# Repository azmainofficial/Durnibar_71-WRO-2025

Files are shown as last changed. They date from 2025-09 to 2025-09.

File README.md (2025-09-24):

# WRO-2025 Future Engineers 🛠️ Durnibar_71 🛠️ 

<p align="center">
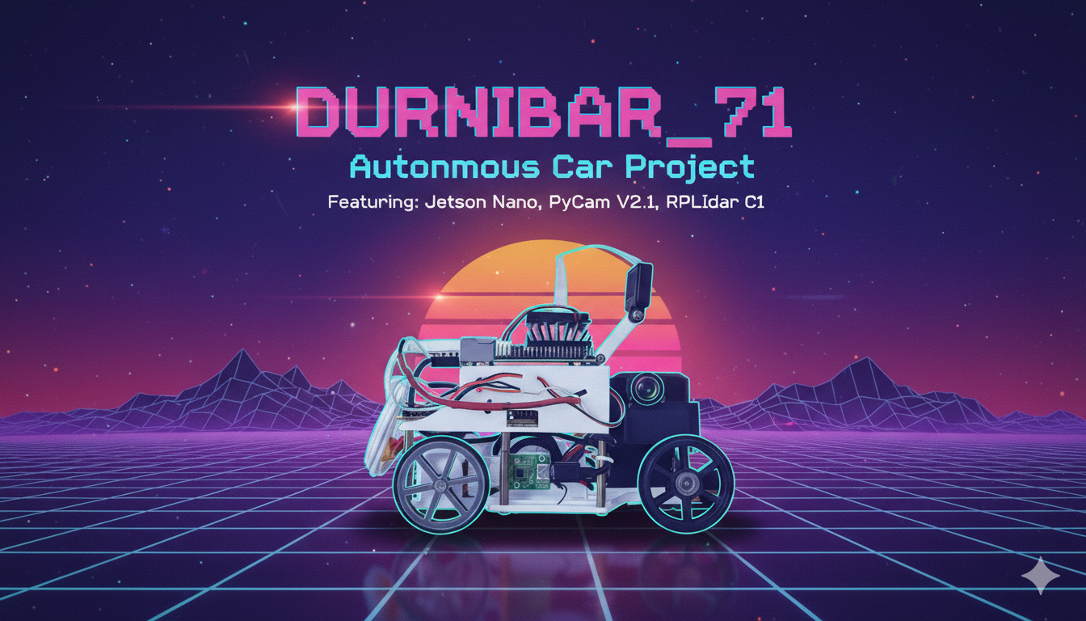
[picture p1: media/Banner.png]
Durnibar_71 Banner
  
</p>

This repository contains our work for the **WRO Future Engineers** category.  
We are building an **Autonomous Car** using **Lidar, Computer Vision, Arduino nano, and Jetson Nano Dev Kit B01**.

---

## 👥 Team - Durnibar_71
- **Azmain Shak Rubayed** – Team Leader, Hardware Developer || [azmiansheikh.nub@gmail.com](mailto:azmiansheikh.nub@gmail.com)
- **Mohit Hasan** - Software Developer || [mohithasan.nub@gmail.com](mailto:azmiansheikh.nub@gmail.com)
---

## 🌟 The Meaning Behind "Durnibar_71"

> *"If the will to win is strong, then any goal can be achieved."*  

This is our **first participation in WRO**, and ever since we began working on this project, we have felt an **indomitable desire** to complete it. That is why we chose the name **"Durnibar"** *(Indomitable / Unstoppable)* — it reflects our relentless effort to give our absolute best, pushing beyond our current limits despite the challenges we faced.  

Every step of this journey has been difficult. We did not have adequate support, so we had to start from scratch and gather every resource on our own. This struggle itself embodies the true spirit of **Durnibar**, a determination to never give up.  

Now, why the **'71**?  
It represents the spirit of the **Bangladesh Liberation War of 1971**. Our independence was achieved not with abundant resources, but with an **unbreakable willpower and focus**. At that time, we were a nation decades behind the rest of the world, yet we shaped our own destiny.  

By carrying the name **Durnibar_71**, we honor that history and commemorate the indomitable willpower of our nation. Just as the people of ’71 stood unstoppable in their pursuit of freedom, we carry the same spirit forward in our journey — in robotics, innovation, and beyond.  

✨ Thank you, everyone, for standing with us in this mission. Together, we move forward with the spirit of **Durnibar_71** — unstoppable, unbreakable, indomitable.  

---

## 📌 Table of Contents
- [🚙 Overview](#-overview)
- [👥 Team Introduction & Information](#-team-introduction--information)
- [📝 Project Description](#-project-description)
- [🔧 Hardware Used](#-hardware-used)
- [💻 Software & Libraries](#-software--libraries)
- [🏆 Competition Challenges](#-competition-challenges)
- [⚠️ Spoilers](#-spoilers)

---
## 🚙 Overview
Our self-driving vehicle prototype, developed for the **WRO Future Engineers 2025** competition, is a fully autonomous robotic system that merges **AI-based decision-making** with precise embedded hardware control.  

The platform is powered by a **Jetson Nano**, serving as the brain for vision and high-level processing, while an **Arduino Nano** handles real-time actuation and sensor management through custom firmware. Sensor data from the **MPU6050 (IMU)** and **QMC5883L (Compass)** is transmitted via serial communication, enabling accurate orientation tracking, drift correction, and smooth navigation.  

The system integrates:  
- **Raspberry Pi Camera v2.1** for image capture and object detection.  
- **MG996R servo motor** and **BTS7960 motor driver** for steering and propulsion control.  
- **1.3" OLED display**, **LED indicators**, **buzzer**, and **3 control buttons** for debugging and feedback.  

Structurally, the vehicle features a **custom PCB** for streamlined connections, alongside a **self-designed chassis**, built for optimal component placement and balance. Power is delivered through a **1000 mAh LiPo battery**, ensuring lightweight mobility and sufficient runtime for competition tasks.  

All functions are distributed between the **Jetson Nano** (core AI/vision algorithms) and the **Arduino Nano** (low-level hardware control), communicating through **PWM, UART, and I²C protocols**. This modular and efficient design ensures the vehicle can **adapt dynamically to track environments**, while maintaining precise actuation and reliable decision-making.  

Altogether, **Durnibar_71** represents an **indomitable and competition-ready platform**, combining embedded intelligence, compact hardware design, and robust autonomy.

## 📂 Repo Structure

- [`media/`](./media) → Images, GIFs, project assets  
- [`models/`](./models) → 3D models, CAD files  
- [`schematic/`](./schematic) → Circuit diagrams, PCB layouts  
- [`software-setup/`](./software-setup) → Installation guides, environment setup  
- [`src/`](./src) → Source code (control, navigation, AI/ML)  
- [`t-photos/`](./t-photos) → Team photos  
- [`v-photos/`](./v-photos) → Vehicle photos  
- [`videos/`](./videos) → Project demo videos  

📜 [`LICENSE`](./LICENSE) → License information  
📖 [`README.md`](./README.md) → Project documentation

## 📸 Visual Views

Here are the reference views of **Durnibar_71**:

| Front View | Back View | Left View |
|---|---|---|
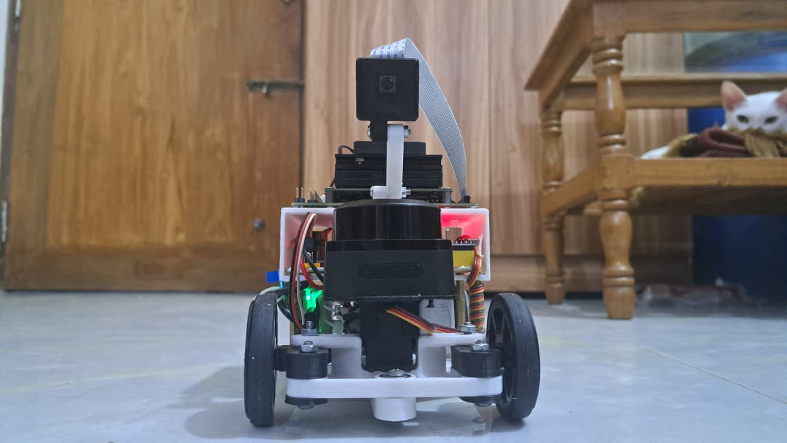
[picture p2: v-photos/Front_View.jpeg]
Front View
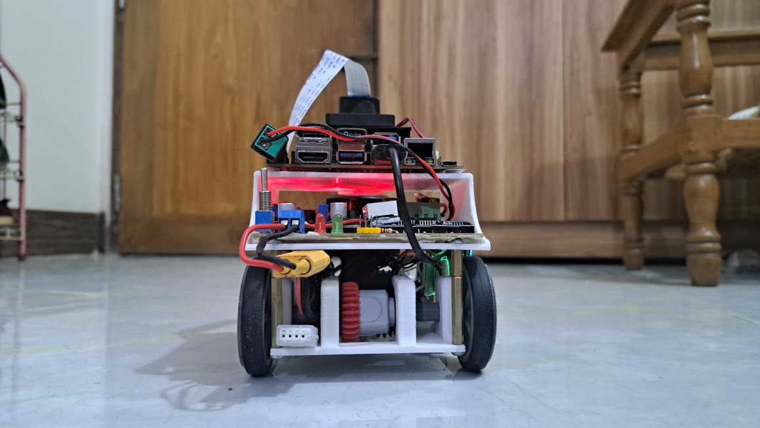
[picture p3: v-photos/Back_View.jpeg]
Back View
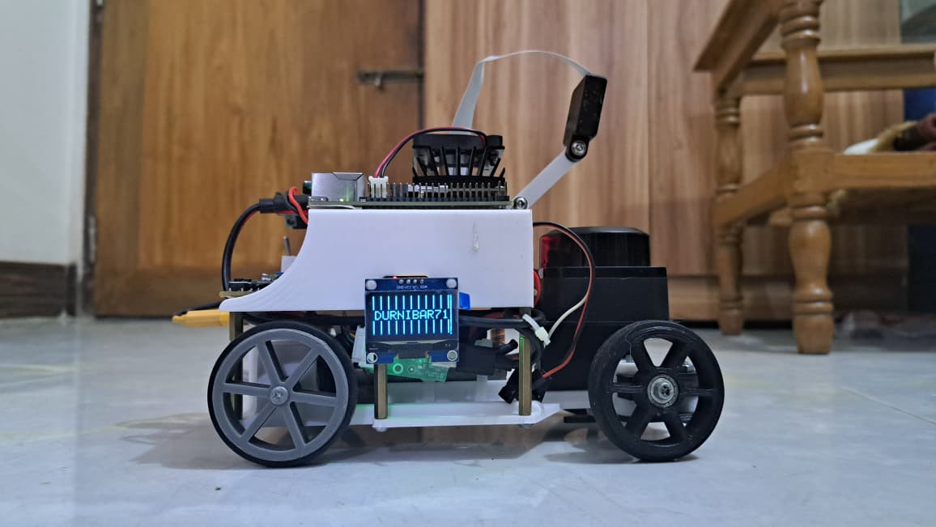
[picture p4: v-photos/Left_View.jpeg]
Left View
|  |  |  |

| Right View | Top View | Bottom View |
|---|---|---|
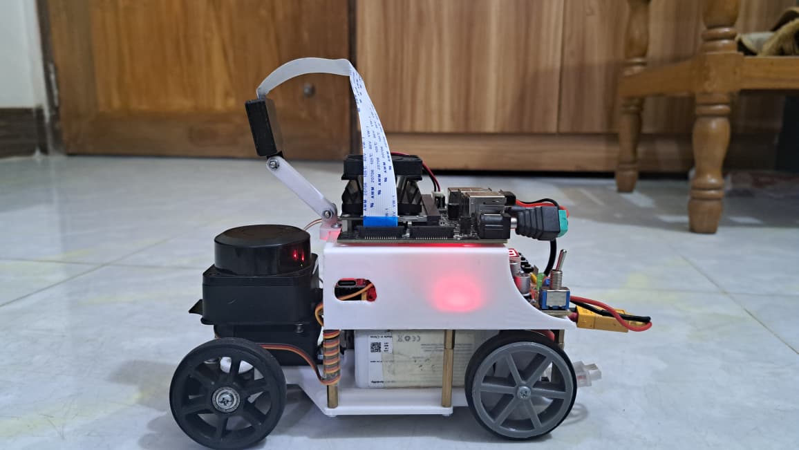
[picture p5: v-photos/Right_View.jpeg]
Right View
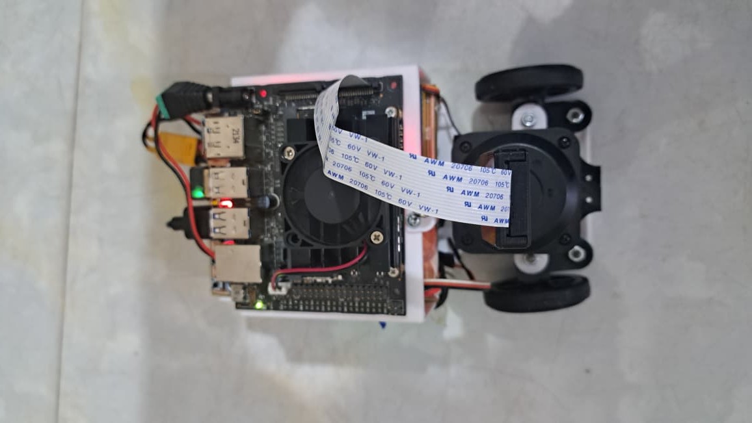
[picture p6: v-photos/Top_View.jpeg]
Top View
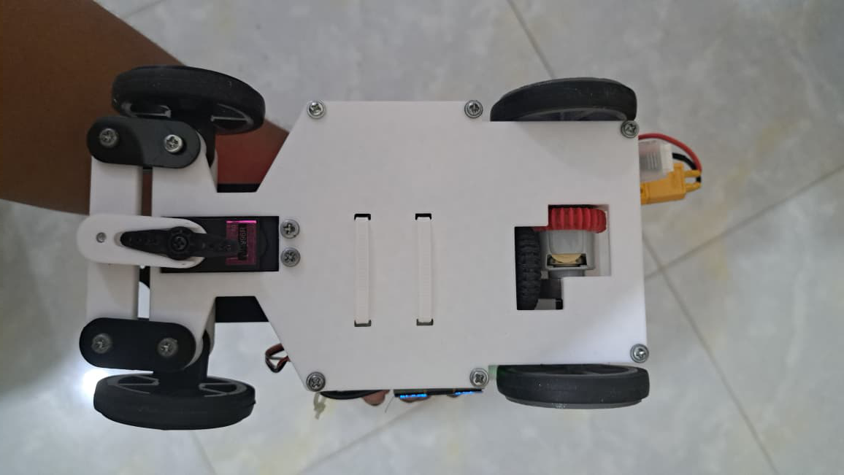
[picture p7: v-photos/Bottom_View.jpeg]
Bottom View
|  |  |  |

---

## 👥 Team Introduction & Information
<table>
  <tr>
    <td align="center" width="300px" style="border: 2px solid #4CAF50; border-radius: 10px; padding: 10px;">
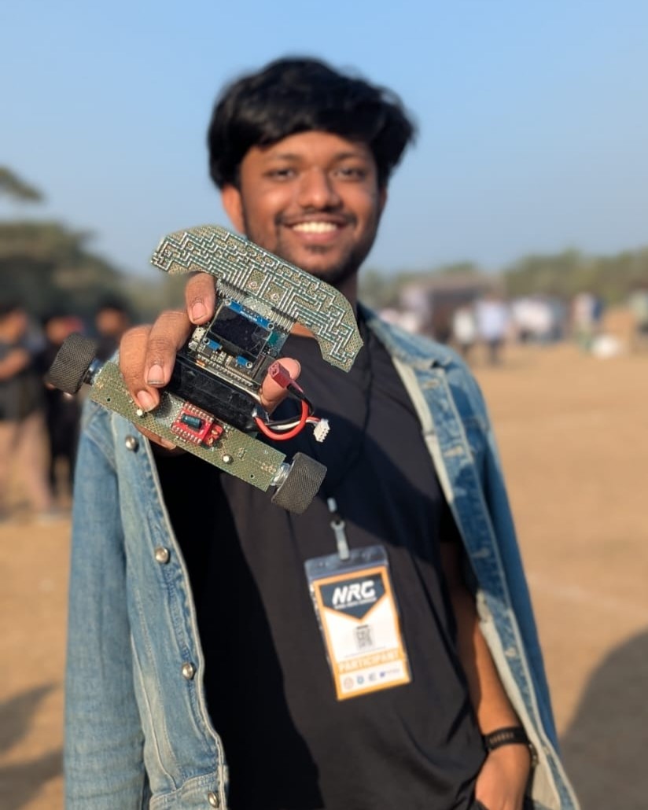
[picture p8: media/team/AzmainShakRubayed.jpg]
Azmain Shak Rubayed
      <br><br>
      <b>AZMAIN SHAK RUBAYED</b><br>
      <i>Team Leader, Hardware Developer</i><br>
      📧 <a href="mailto:azmiansheikh.nub@gmail.com">azmiansheikh.nub@gmail.com</a>
    </td>
    <td align="center" width="300px" style="border: 2px solid #4CAF50; border-radius: 10px; padding: 10px;">
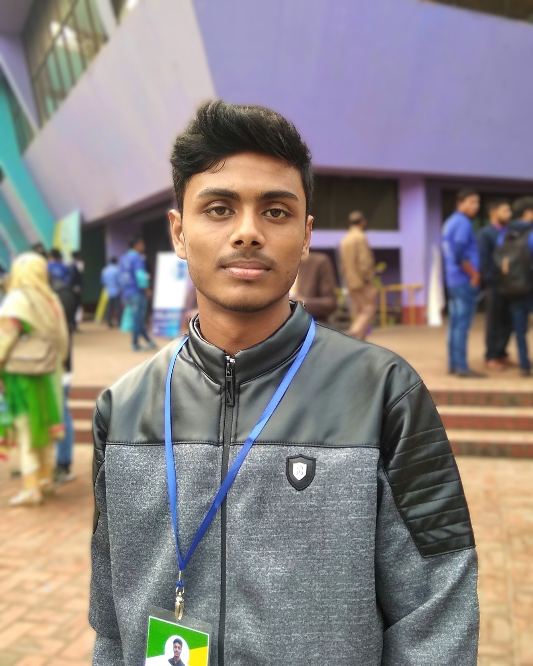
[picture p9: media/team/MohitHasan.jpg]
Mohit Hasan
      <br><br>
      <b>MOHIT HASAN</b><br>
      <i>Software Developer</i><br>
      📧 <a href="mailto:mohithasan.nub@gmail.com">mohithasan.nub@gmail.com</a>
    </td>
  </tr>
</table>

---

## 📝 Project Description

### 💡 Problem Statement
How can a robot dynamically avoid both **visible and invisible obstacles** in real-time using **multi-sensor fusion**?  

The challenge is to design a system that can **sense, process, and act** efficiently in dynamic environments, integrating inputs from IMU, compass, camera, and other sensors to make split-second decisions while navigating autonomously.

### 🎯 Goals
- Implement **real-time obstacle detection and avoidance** using multiple sensors (MPU6050, QMC5883L, Raspberry Pi Camera).  
- Achieve **smooth navigation and path planning** using sensor fusion and AI algorithms on the Jetson Nano.  
- Enable **Arduino Nano** to handle low-level actuation and immediate response while syncing with the Jetson Nano.  
- Build a **modular and scalable robot architecture** that can adapt to changing track conditions.  
- Demonstrate a **robust autonomous system** suitable for WRO Future Engineers competition tasks.

## 🧩 Components & Hardware

| Component | Description | Specifications | Purpose | Image |
|---|---|---|---|---|
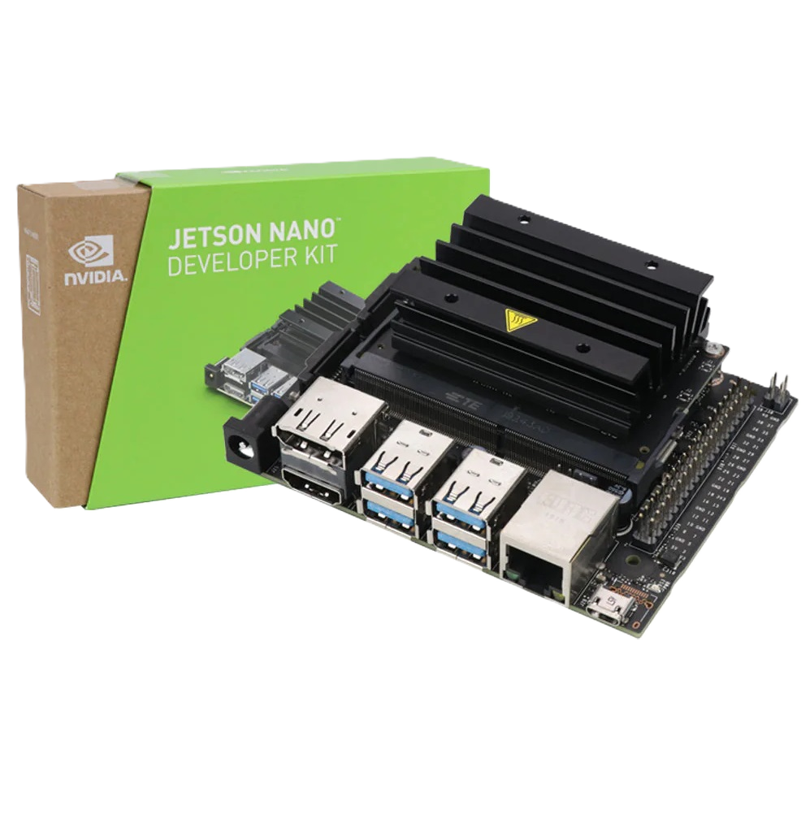
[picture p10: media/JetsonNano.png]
| **NVIDIA Jetson Nano** | Central processing unit handling high-level computations, including image processing and decision-making | Quad-core ARM Cortex-A57 CPU, 128-core Maxwell GPU, 4GB LPDDR4 RAM, Ubuntu-based OS | Executes ROS nodes, processes camera inputs, manages autonomous navigation algorithms |   NVIDIA Jetson Nano |
| **Raspberry Pi Camera V2.1** | Provides real-time video feed for object detection and lane tracking | 8MP Sony IMX219 sensor, 1080p30/720p60/640x480p90 video modes | Captures visual data for Jetson Nano processing |
| **MPU6050 (Gyroscope + Accelerometer)** | Measures robot orientation and motion | 3-axis gyroscope, 3-axis accelerometer, I²C interface | Provides orientation data for navigation and stability |
| **QMC5883L (Magnetometer)** | Measures magnetic field to determine heading | 3-axis magnetometer, I²C interface | Assists in compass heading determination |
| **Arduino Nano** | Microcontroller for low-level motor control and sensor interfacing | ATmega328P, 14 digital I/O pins, 8 analog inputs, 5V operating voltage | Interfaces with sensors and motor drivers to control movement |
| **MG996R Servo Motor** | Provides steering control | Torque: 9.4 kg·cm, Operating voltage: 4.8–6.8V, Speed: 0.2s/60° | Adjusts the robot's steering mechanism |
| **BTS7960 Motor Driver** | Drives robot wheels via DC motors | Dual H-Bridge, 5.5–40V operating voltage, Continuous current: 43A | Controls speed and direction of the robot |
| **1000mAh LiPo Battery** | Powers the robot | Voltage: 3.7V, Capacity: 1000mAh, Discharge rate: 25C | Provides portable power to the robot |
| **Custom PCB** | Houses circuit components and connections | Custom layout for all components | Ensures reliable electrical connections and compact design |

## Software & Libraries
List your software/libraries here...

## Competition Challenges
In the WRO Future Engineers competition, we tackle real-world robotics challenges using autonomous vehicles. The main challenge is to design, build, and program a robot to complete complex navigation and task-based missions.

## Spoilers
Add spoilers or extras here...

---

## 🛠️ Features
- Lane detection with OpenCV
- Obstacle detection using Lidar/Ultrasonic
- PID speed & steering control
- Simulation with ROS + Gazebo
- Autonomous navigation with waypoints

---

## 📜 License
This project is licensed under the **MIT License** – see the [LICENSE](LICENSE) file for details.

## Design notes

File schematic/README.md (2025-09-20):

# 🛠️ Schematics & PCB Layout – Durnibar_71

This directory contains the circuit schematics, PCB layouts, and assembly previews for **Durnibar_71 – WRO Future Engineers 2025**.

---

## 📌 Schematic Diagram
The main circuit schematic designed for power management, motor driver, and sensor integration.

<p align="center">
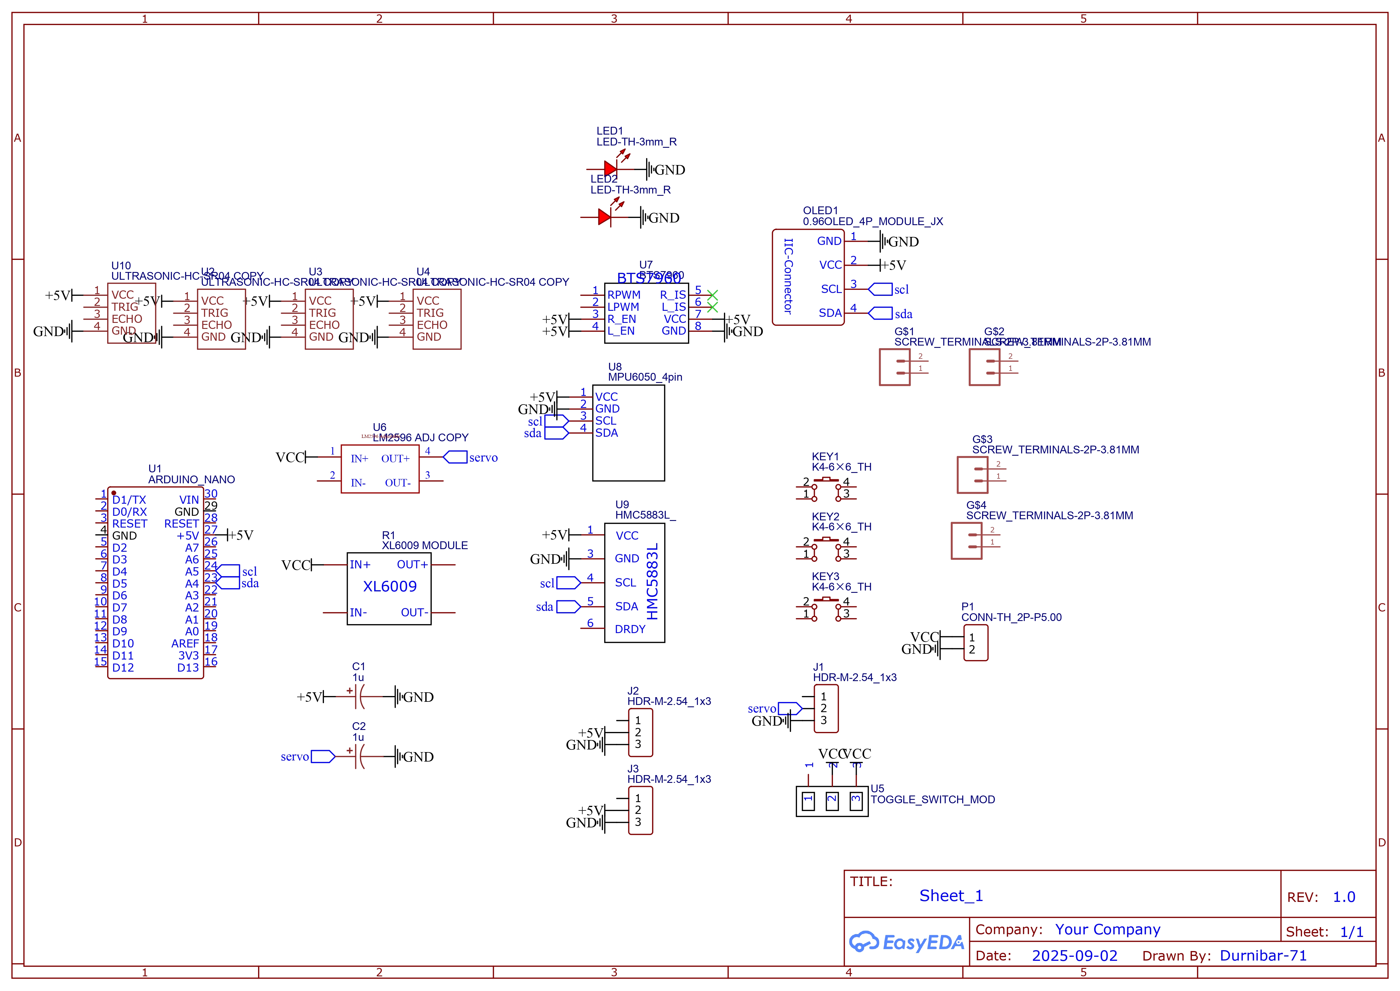
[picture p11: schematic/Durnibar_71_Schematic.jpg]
Schematic
  
</p>

---

## 📌 PCB Layouts

| Top View | Bottom View |
|---|---|
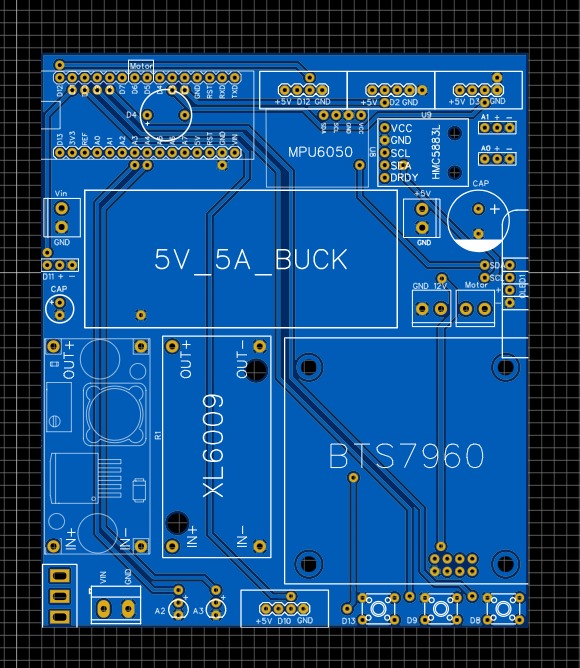
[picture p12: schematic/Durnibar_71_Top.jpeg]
Top View
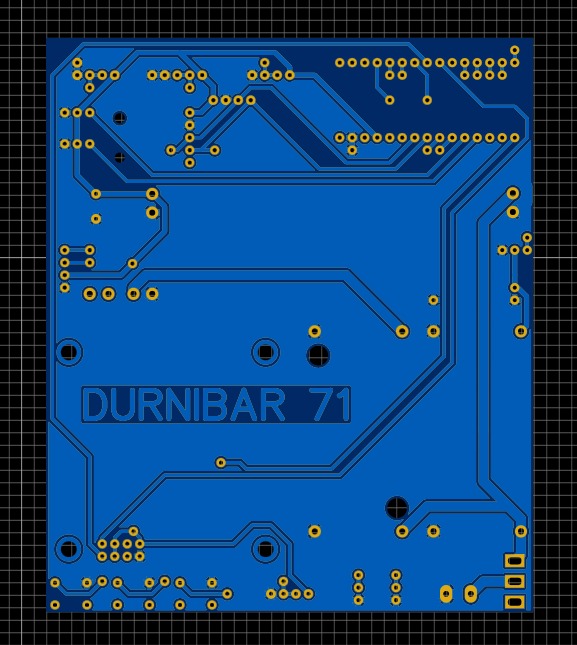
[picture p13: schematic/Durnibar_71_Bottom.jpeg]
Bottom View
|  |  |

---

## 📌 Assembly Previews

| Assembled Top | Assembled Bottom |
|---|---|
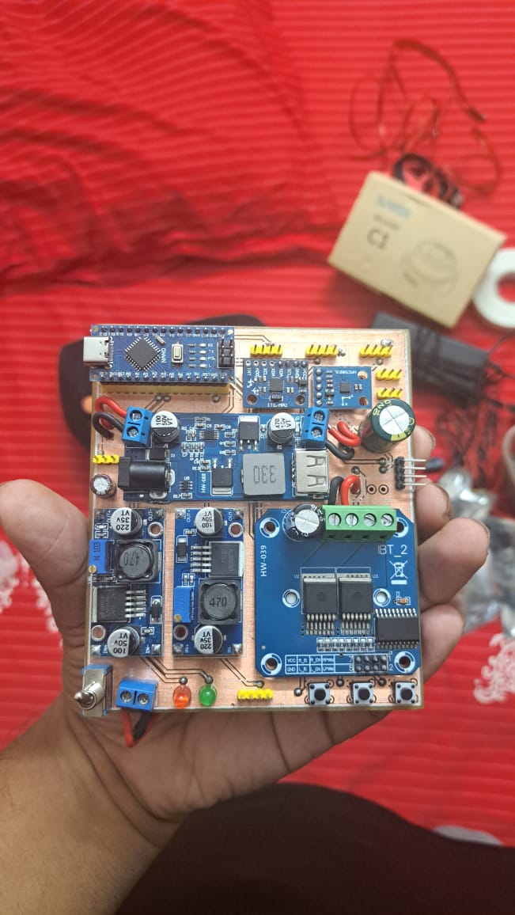
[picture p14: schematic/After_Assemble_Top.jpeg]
Assembled Top
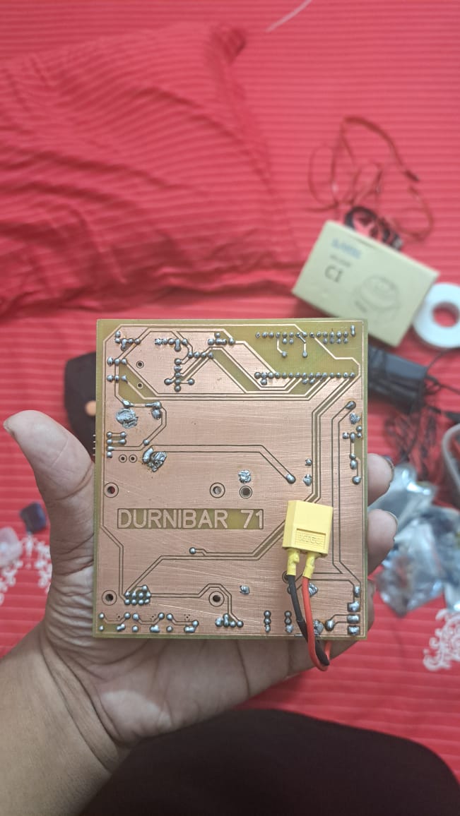
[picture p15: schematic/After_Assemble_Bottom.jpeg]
Assembled Bottom
|  |  |

---

## 📌 JSON Design File
The KiCad/Eagle/Other EDA export file for PCB:

- [Durnibar_71.json](./Durnibar_71.json)

---

✨ This section documents the **electronics backbone** of Durnibar_71, ensuring proper connectivity between **Jetson Nano, Arduino Nano, MPU6050, QMC5883L, OLED, Motor Driver, Servo, and sensors**.

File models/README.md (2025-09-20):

# ⚙️ 3D Models – Durnibar_71

This directory contains the **custom 3D models** designed for the **Durnibar_71 autonomous vehicle**.  
Each part has both a **3D preview (.gif)** and a **downloadable CAD model (.stl)**.  

---

## 📊 Quick Reference Table

| Component | Preview | STL File |
|---|---|---|
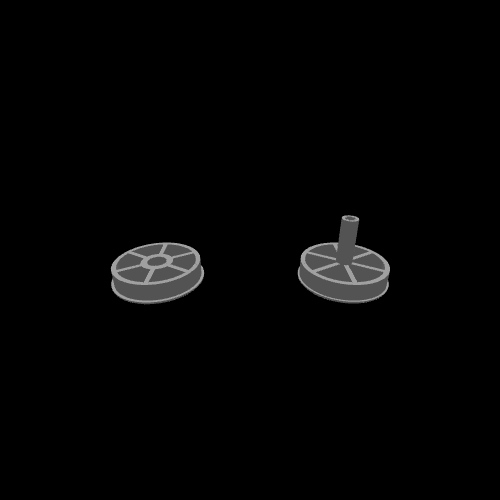
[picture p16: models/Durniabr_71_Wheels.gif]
Wheel
| 🛞 Wheel |  | [Durniabr_71_Wheels.stl](./Durniabr_71_Wheels.stl) |
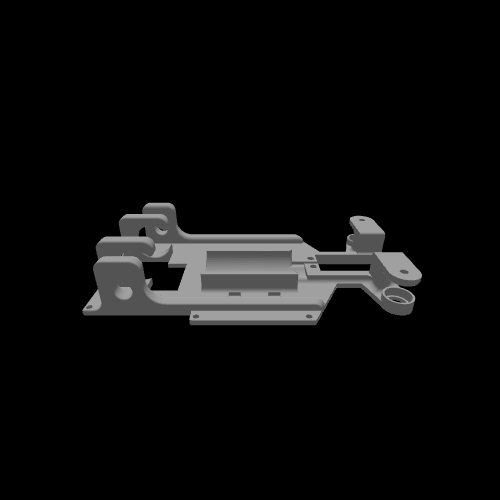
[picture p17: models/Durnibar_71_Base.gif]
Base
| 🏎️ Base Frame |  | [Durnibar_71_Base.stl](./Durnibar_71_Base.stl) |
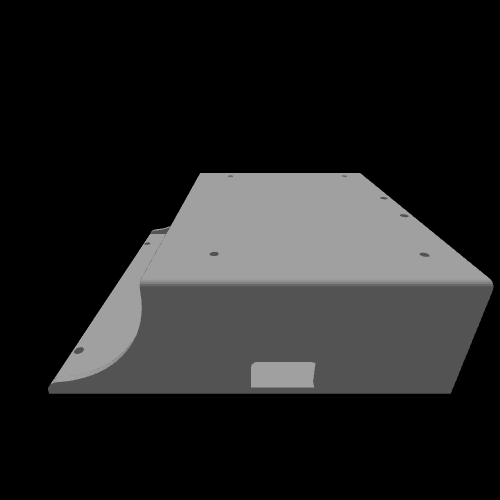
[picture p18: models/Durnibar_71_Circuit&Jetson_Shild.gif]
Circuit
| 🔌 Circuit & Jetson Shield |  | [Durnibar_71_Circuit&Jetson_Shild.stl](./Durnibar_71_Circuit&Jetson_Shild.stl) |
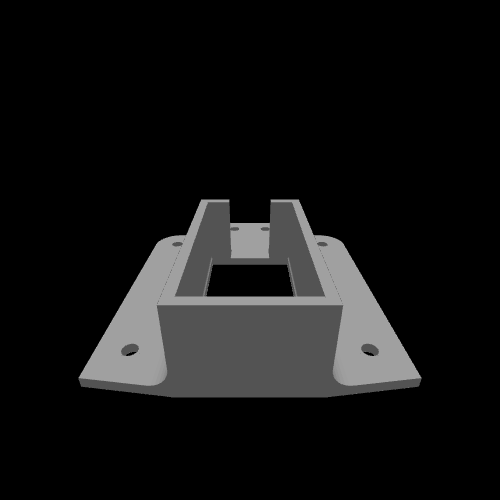
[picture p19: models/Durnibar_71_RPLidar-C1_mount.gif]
RPLidar
| 🛰️ RPLidar C1 Mount |  | [Durnibar_71_RPLidar-C1_mount.stl](./Durnibar_71_RPLidar-C1_mount.stl) |
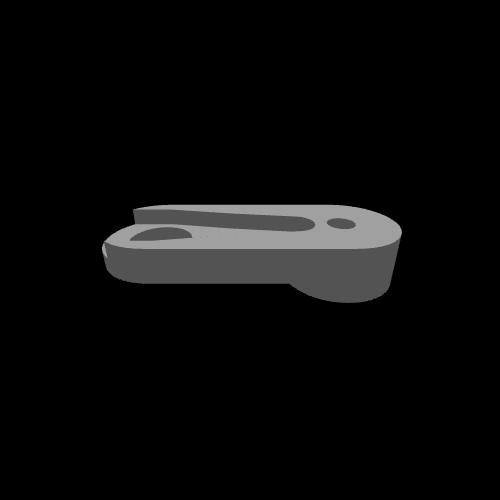
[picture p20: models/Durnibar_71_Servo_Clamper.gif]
Servo
| ⚙️ Servo Clamper |  | [Durnibar_71_Servo_Clamper.stl](./Durnibar_71_Servo_Clamper.stl) |
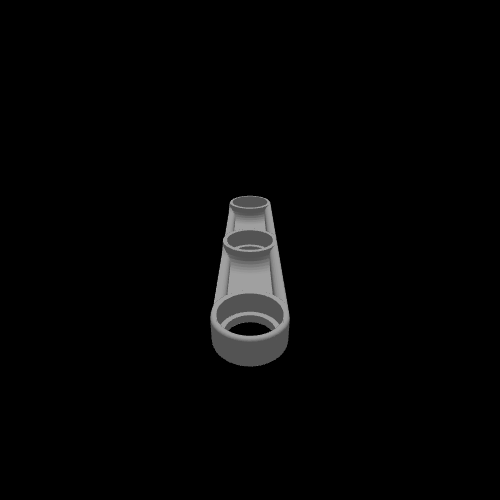
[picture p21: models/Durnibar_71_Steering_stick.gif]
Steering
| 🎮 Steering Stick |  | [Durnibar_71_Steering_stick.stl](./Durnibar_71_Steering_stick.stl) |
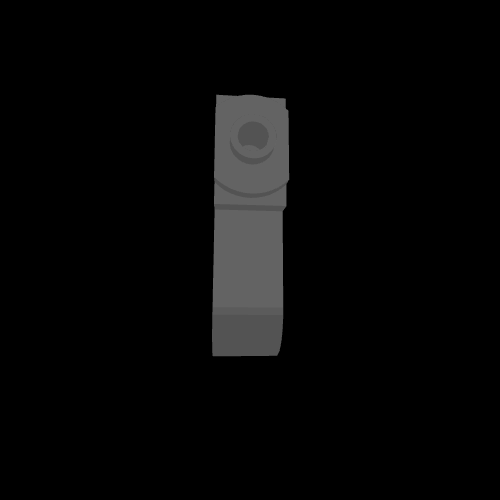
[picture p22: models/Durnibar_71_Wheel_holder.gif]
Holder
| 🔩 Wheel Holder |  | [Durnibar_71_Wheel_holder.stl](./Durnibar_71_Wheel_holder.stl) |
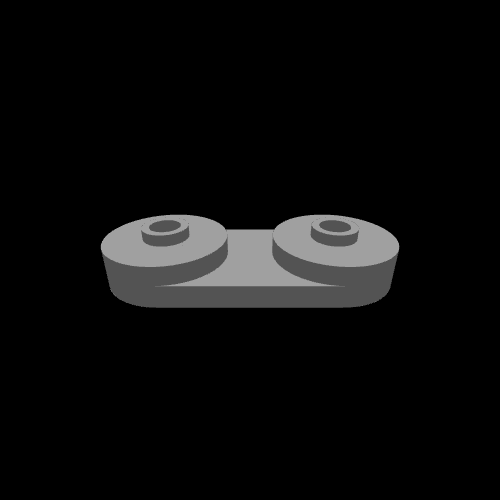
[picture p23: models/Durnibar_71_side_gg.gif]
Side
| 🛡️ Side Guard |  | [Durnibar_71_side_gg.stl](./Durnibar_71_side_gg.stl) |

---

## 🛞 Wheel
<p align="center">
  Wheel
</p>

- File: [Durniabr_71_Wheels.stl](./Durniabr_71_Wheels.stl)  
- Role: Custom wheel designed for traction and stability on competition tracks.  

---

## 🏎️ Base Frame
<p align="center">
  Base
</p>

- File: [Durnibar_71_Base.stl](./Durnibar_71_Base.stl)  
- Role: Lightweight chassis optimized for balance, wiring, and modular mounting.  

---

## 🔌 Circuit & Jetson Shield
<p align="center">
  Circuit Shield
</p>

- File: [Durnibar_71_Circuit&Jetson_Shild.stl](./Durnibar_71_Circuit&Jetson_Shild.stl)  
- Role: Secure mount for **custom PCB + Jetson Nano**, ensuring clean integration.  

---

## 🛰️ RPLidar C1 Mount
<p align="center">
  RPLidar Mount
</p>

- File: [Durnibar_71_RPLidar-C1_mount.stl](./Durnibar_71_RPLidar-C1_mount.stl)  
- Role: Provides stable positioning for **RPLidar C1 sensor**.  

---

## ⚙️ Servo Clamper
<p align="center">
  Servo Clamper
</p>

- File: [Durnibar_71_Servo_Clamper.stl](./Durnibar_71_Servo_Clamper.stl)  
- Role: Holds servo motors in place with precision alignment.  

---

## 🎮 Steering Stick
<p align="center">
  Steering Stick
</p>

- File: [Durnibar_71_Steering_stick.stl](./Durnibar_71_Steering_stick.stl)  
- Role: Mechanism for steering control linked to servo clampers.  

---

## 🔩 Wheel Holder
<p align="center">
  Wheel Holder
</p>

- File: [Durnibar_71_Wheel_holder.stl](./Durnibar_71_Wheel_holder.stl)  
- Role: Provides durability and stability for wheel mounting.  

---

## 🛡️ Side Guard
<p align="center">
  Side Guard
</p>

- File: [Durnibar_71_side_gg.stl](./Durnibar_71_side_gg.stl)  
- Role: Side protection for wiring and components, preventing collision damage.  

---

## 📌 Notes
- All parts are **custom-designed** for Durnibar_71.  
- Optimized for **3D printing** with minimal support requirements.  
- Ensures a **strong, modular, and competition-ready** robot structure.

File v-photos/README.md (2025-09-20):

## 📸 Visual Views

Here are the reference views of **Durnibar_71**:

| Front View | Back View | Left View |
|---|---|---|
| Front View | Back View | Left View |

| Right View | Top View | Bottom View |
|---|---|---|
| Right View | Top View | Bottom View |

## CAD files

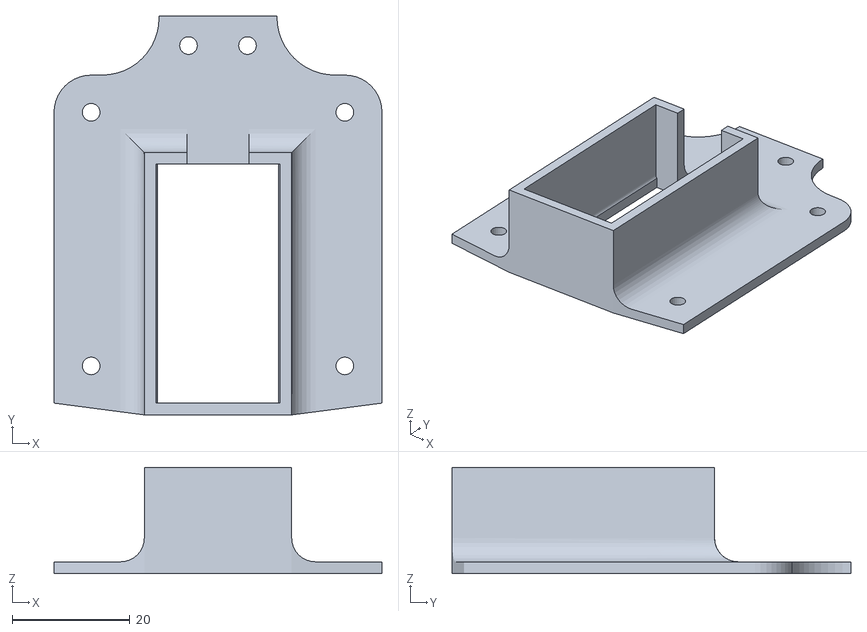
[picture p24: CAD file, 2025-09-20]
models/Durnibar_71_RPLidar-C1_mount.stl
55.6 x 67.6 x 18.0

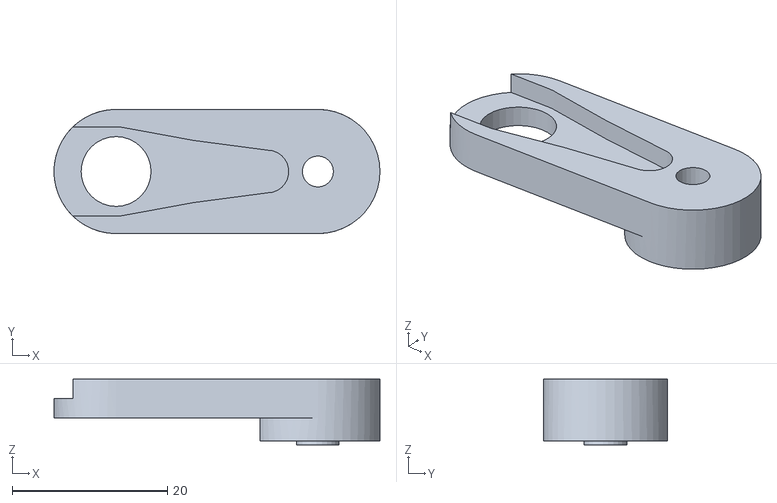
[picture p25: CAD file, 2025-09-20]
models/Durnibar_71_Servo_Clamper.stl
42.0 x 16.0 x 8.50

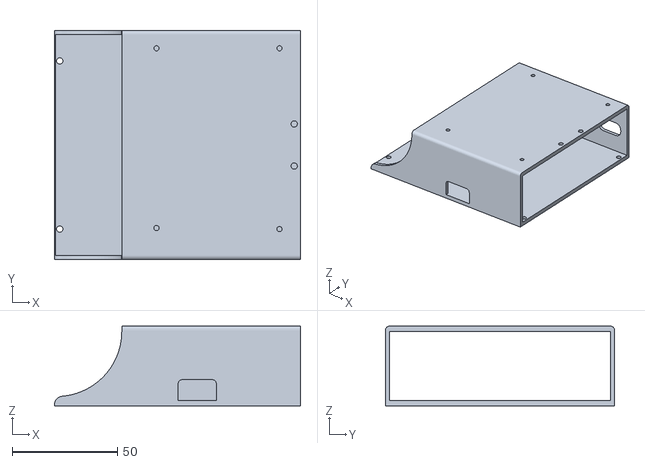
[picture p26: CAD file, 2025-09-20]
models/Durnibar_71_Circuit&Jetson_Shild.stl
117.0 x 109.0 x 38.0

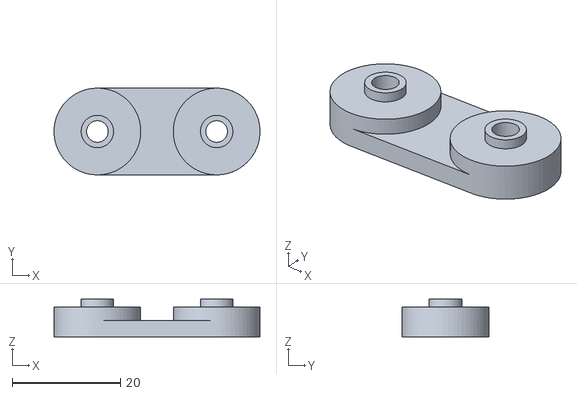
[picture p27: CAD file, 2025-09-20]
models/Durnibar_71_side_gg.stl
38.0 x 16.0 x 7.00

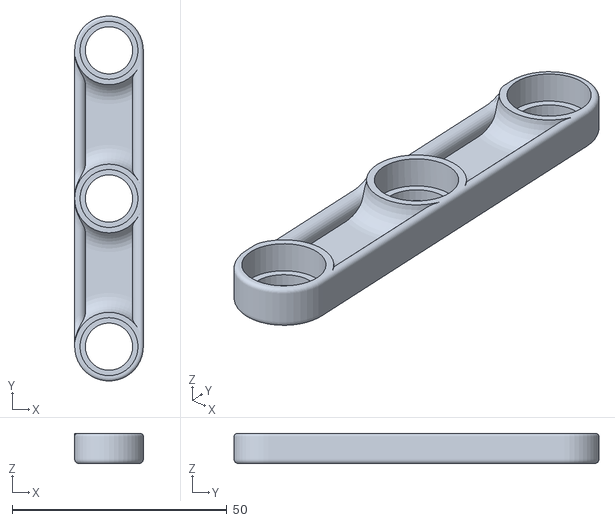
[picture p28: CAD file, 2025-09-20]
models/Durnibar_71_Steering_stick.stl
16.0 x 85.0 x 7.00

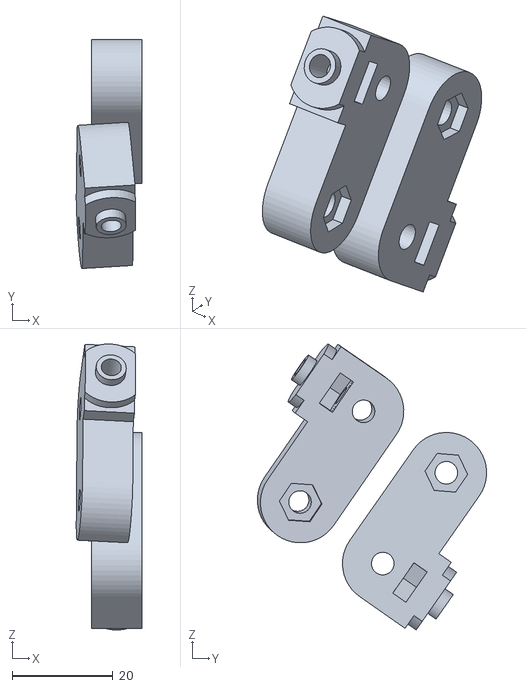
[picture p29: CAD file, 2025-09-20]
models/Durnibar_71_Wheel_holder.stl
13.0 x 45.5 x 56.8

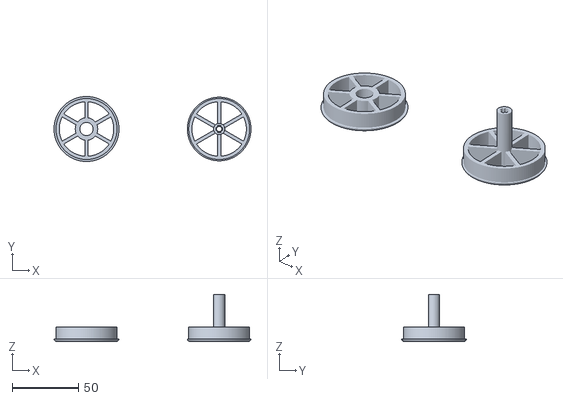
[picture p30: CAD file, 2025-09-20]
models/Durniabr_71_Wheels.stl
148.5 x 49.0 x 35.5

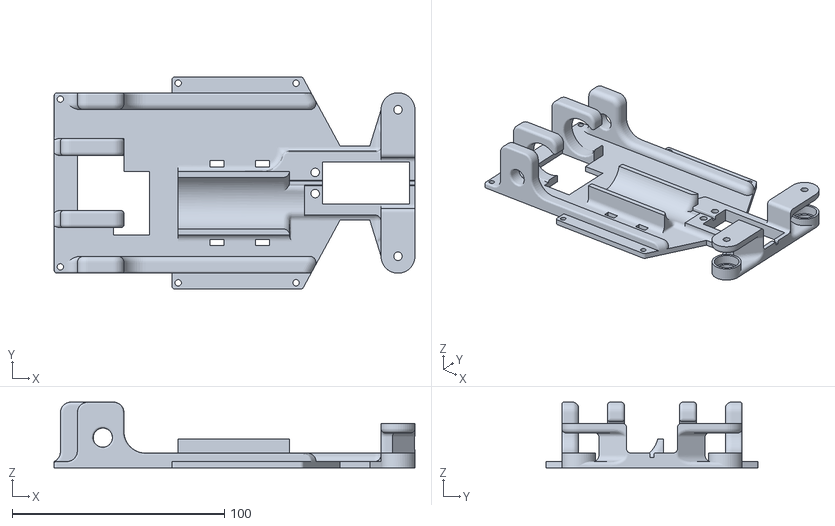
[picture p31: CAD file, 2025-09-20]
models/Durnibar_71_Base.stl
170.0 x 100.0 x 31.0

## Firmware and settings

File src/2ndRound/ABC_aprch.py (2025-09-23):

#!/usr/bin/env python3

import serial
import serial.tools.list_ports
from rplidar import RPLidar, RPLidarException
import time
import sys
import argparse
import cv2
import numpy as np
import math

# ===================== CONFIGURATIONS =====================
# General
RESIZE_WIDTH = 640
DIST_THRESHOLD_CM = 30.0 # Decision distance for vision system

# Vision system
KNOWN_WIDTH_CM = 2.08            # Real-world block width in cm
MIN_CONTOUR_AREA = 500           # Minimum contour size
FOCAL_LENGTH_PX = 750.0         # Adjust based on camera calibration

# HSV color ranges for vision system
lower_green = np.array([35, 80, 50])
upper_green = np.array([85, 255, 255])
lower_red1 = np.array([0, 150, 100])
upper_red1 = np.array([10, 255, 255])
lower_red2 = np.array([170, 150, 100])
upper_red2 = np.array([180, 255, 255])

# Hardware connections
LIDAR_PORT = "/dev/ttyUSB0"
LIDAR_BAUD = 460800
ARDUINO_PORT = "/dev/ttyUSB1"
ARDUINO_BAUD = 9600

# Control system
SERVO_CENTER = 110
MAX_ADJ = 30


# ===================== CONTROL CLASSES & UTILS =====================
class KalmanFilter:
      """A Kalman Filter for fusing IMU data (gyro and magnetometer)."""
      def __init__(self, Q_angle, Q_bias, R_measure):
            self.Q_angle = Q_angle
            self.Q_bias = Q_bias
            self.R_measure = R_measure
            self.angle = 0.0
            self.bias = 0.0
            self.P = [[0.0, 0.0], [0.0, 0.0]]
            self.last_time = time.time()

      def filter(self, new_angle, new_rate, dt):
            """Updates the filter with new sensor data."""
            self.angle += dt * (new_rate - self.bias)
            self.P[0][0] += dt * (dt * self.P[1][1] - self.P[0][1] - self.P[1][0] + self.Q_angle)
            self.P[0][1] -= dt * self.P[1][1]
            self.P[1][0] -= dt * self.P[1][1]
            self.P[1][1] += self.Q_bias * dt
             
            S = self.P[0][0] + self.R_measure
            if S == 0:
                  return self.angle
            K = [self.P[0][0] / S, self.P[1][0] / S]
            y = new_angle - self.angle
             
            self.angle += K[0] * y
            self.bias += K[1] * y
             
            P00_temp = self.P[0][0]
            P01_temp = self.P[0][1]
             
            self.P[0][0] -= K[0] * P00_temp
            self.P[0][1] -= K[0] * P01_temp
            self.P[1][0] -= K[1] * P00_temp
            self.P[1][1] -= K[1] * self.P[1][1]

            return self.angle


class PIDController:
      """A basic PID controller for calculating steering adjustments."""
      def __init__(self, kp, ki, kd):
            self.kp = kp
            self.ki = ki
            self.kd = kd
            self.last_error = 0
            self.integral = 0
            self.integral_limit = 10

      def calculate_output(self, error):
            proportional = self.kp * error
            self.integral += error
            self.integral = max(-self.integral_limit, min(self.integral, self.integral_limit))
            integral_term = self.ki * self.integral
            derivative = self.kd * (error - self.last_error)
            self.last_error = error
            return proportional + integral_term + derivative


def parse_sensor_data(data):
      """Parses a string of serial data into a dictionary of sensor values."""
      values = {}
      parts = data.strip().split(',')
      for part in parts:
            try:
                  key, val = part.split(':')
                  values[key] = float(val)
            except ValueError:
                  pass
      return values


def safe_write(serial_conn, cmd):
      """Write safely to serial without crashing."""
      if serial_conn and serial_conn.is_open:
            try:
                  serial_conn.write(cmd.encode("utf-8"))
            except Exception:
                  pass


# ===================== VISION FUNCTIONS =====================
def color_mask(hsv, color_name):
      """Creates a binary mask for a specified color."""
      if color_name == 'green':
            return cv2.inRange(hsv, lower_green, upper_green)
      elif color_name == 'red':
            m1 = cv2.inRange(hsv, lower_red1, upper_red1)
            m2 = cv2.inRange(hsv, lower_red2, upper_red2)
            return cv2.bitwise_or(m1, m2)
      return None


def shortest_side(obj):
      """Calculates the shortest side of a rotated rectangle."""
      w, h = obj['w_rot'], obj['h_rot']
      short, long = (w, h) if w < h else (h, w)
      return short if long/short > 2 else (w+h)/2


def find_objects(frame, color_name):
      """Detects and returns objects of a specific color."""
      hsv = cv2.cvtColor(frame, cv2.COLOR_BGR2HSV)
      mask = color_mask(hsv, color_name)
      mask = cv2.erode(mask, None, iterations=2)
      mask = cv2.dilate(mask, None, iterations=2)
      contours, _ = cv2.findContours(mask, cv2.RETR_EXTERNAL, cv2.CHAIN_APPROX_SIMPLE)
      objs = []
      for c in contours:
            if cv2.contourArea(c) < MIN_CONTOUR_AREA:
                  continue
            rect = cv2.minAreaRect(c)
            (rx, ry), (w_rot, h_rot), _ = rect
            box = cv2.boxPoints(rect).astype(int)
            M = cv2.moments(c)
            cx = int(M["m10"]/M["m00"]) if M["m00"] > 0 else int(rx)
            cy = int(M["m01"]/M["m00"]) if M["m00"] > 0 else int(ry)
            objs.append({'cx':cx,'cy':cy,'w_rot':w_rot,'h_rot':h_rot,
                                'box':box,'color':color_name,'contour':c})
      return objs


def process_frame(frame):
      """Processes a video frame to detect colored blocks and measure distance."""
      # Resize frame
      h0, w0 = frame.shape[:2]
      scale = RESIZE_WIDTH / float(w0)
      RESIZE_HEIGHT = int(round(h0 * scale))
      frame = cv2.resize(frame, (RESIZE_WIDTH, RESIZE_HEIGHT))
      fx = FOCAL_LENGTH_PX

      # Detect objects
      red_objs = find_objects(frame, 'red')
      green_objs = find_objects(frame, 'green')
      all_objs = red_objs + green_objs

      nearest = None
      min_dist = float('inf')

      # Analyze objects
      for obj in all_objs:
            width_px = shortest_side(obj)
            if width_px <= 0:
                  continue
            distance_cm = (KNOWN_WIDTH_CM * fx) / width_px

            if distance_cm < min_dist:
                  min_dist = distance_cm
                  nearest = {
                        "color": obj['color'],
                        "dist": distance_cm,
                        "cx": obj['cx'],
                        "cy": obj['cy']
                  }

            # Draw object box
            cv2.drawContours(frame, [obj['box']], 0,
                                      (0,255,0) if obj['color']=='green' else (0,0,255), 2)
            cv2.circle(frame,(obj['cx'],obj['cy']),5,(255,255,255),-1)

      # Decision based on vision
      vision_signal = None
      vision_action_text = "No Obstacle"
      if nearest and nearest["dist"] <= DIST_THRESHOLD_CM:
            if nearest["color"] == "green":
                  vision_action_text = "Move RIGHT (green block)"
                  vision_signal = "A140\n" # Command for a hard right turn
            elif nearest["color"] == "red":
                  vision_action_text = "Move LEFT (red block)"
                  vision_signal = "A80\n" # Command for a hard left turn

      # Add debug text to the frame
      cv2.putText(frame, vision_action_text, (10, RESIZE_HEIGHT - 20),
                        cv2.FONT_HERSHEY_SIMPLEX, 0.7, (0, 255, 255), 2)
      if nearest:
            cv2.putText(frame,
                              f"Nearest: {nearest['color']} {nearest['dist']:.1f}cm",
                              (10, 40), cv2.FONT_HERSHEY_SIMPLEX, 0.7, (255, 255, 0), 2)

      return vision_signal, frame


# ===================== NAVIGATION FUNCTIONS =====================
def wall_following(scan, pid, servo_center, max_adjustment):
      """Compute steering angle using wall-following."""
      left_distances = [d/1000.0 for q, a, d in scan if 60 <= a <= 90 and d > 100]
      right_distances = [d/1000.0 for q, a, d in scan if 270 <= a <= 300 and d > 100]

      if left_distances and right_distances:
            avg_left = sum(left_distances) / len(left_distances)
            avg_right = sum(right_distances) / len(right_distances)
            error = avg_left - avg_right
            steer = pid.calculate_output(error)
            clamped = max(-1.0, min(steer, 1.0))
            final_angle = servo_center + (clamped * max_adjustment)
            return f"A{int(max(80, min(140, final_angle)))}\n"
      return None


def imu_fallback(imu_data, kalman, dt, servo_center):
      """Compute steering angle using IMU fallback."""
      if "H" not in imu_data or "GY" not in imu_data:
            return None

      imu_data["H"] = 360 - imu_data["H"]
      fused = kalman.filter(imu_data["H"], imu_data["GY"], dt)

      target_heading = 0.0
      error = target_heading - fused
      if error > 180: error -= 360
      elif error < -180: error += 360

      steering_adjustment = error * 0.5
      final_angle = servo_center + steering_adjustment
      return f"A{int(max(80, min(140, final_angle)))}\n"


# ===================== MAIN LOOP =====================
def main():
      print("Starting robot control script...")
      # Controllers
      pid = PIDController(1.5, 0.01, 1.0)
      kalman = KalmanFilter(0.001, 0.003, 0.03)

      # Connect to devices
      print("Initializing hardware...")
      cap = cv2.VideoCapture(("nvarguscamerasrc ! video/x-raw(memory:NVMM), width=640, height=480, format=NV12, framerate=30/1 ! "
                 "nvvidconv flip-method=0 ! video/x-raw, format=BGRx ! "
                 "videoconvert ! video/x-raw, format=BGR ! appsink"), cv2.CAP_GSTREAMER)

      if not cap.isOpened():
            print("? Failed to open camera with GStreamer pipeline")
            sys.exit(1)

      lidar, arduino = None, None
      while lidar is None or arduino is None:
            try:
                  if lidar is None:
                        print("Connecting LiDAR...")
                        lidar = RPLidar(LIDAR_PORT, baudrate=LIDAR_BAUD)
                        lidar.get_info()
                        print("? LiDAR connected")
                  if arduino is None:
                        print("Connecting Arduino...")
                        arduino = serial.Serial(ARDUINO_PORT, ARDUINO_BAUD, timeout=1)
                        time.sleep(2)
                        print("? Arduino connected")
                        safe_write(arduino, "RL\n") # Start motor command
                        print("Sent: RL")
                  break
            except Exception as e:
                  print(f"Connection error: {e}, retrying in 5 seconds...")
                  time.sleep(5)
      
      last_time = time.time()
      is_avoiding = False
      try:
            # Use lidar.iter_scans() as the main loop driver
            for scan in lidar.iter_scans():
                  dt = time.time() - last_time
                  last_time = time.time()

                  # 1. Process vision data
                  ret, frame = cap.read()
                  if not ret:
                        print("? Camera frame not received")
                        continue
                  vision_command, processed_frame = process_frame(frame)

                  # 2. Read IMU data
                  imu_data = {}
                  if arduino.in_waiting:
                        line = arduino.readline().decode("utf-8").strip()
                        imu_data = parse_sensor_data(line)

                  # 3. Make the final decision based on a hierarchy
                  final_command = None
                  
                  # If a block is seen within the threshold, enter avoidance mode
                  if vision_command:
                        is_avoiding = True
                        final_command = vision_command
                  # If we were avoiding, but no block is now visible, switch back to navigation
                  elif is_avoiding:
                        is_avoiding = False
                        final_command = wall_following(scan, pid, SERVO_CENTER, MAX_ADJ) or \
                                                imu_fallback(imu_data, kalman, dt, SERVO_CENTER) or "S\n"
                  # If not in avoidance mode, proceed with normal navigation
                  else:
                        final_command = wall_following(scan, pid, SERVO_CENTER, MAX_ADJ) or \
                                                imu_fallback(imu_data, kalman, dt, SERVO_CENTER) or "S\n"

                  safe_write(arduino, final_command)
                  print(f"Sent: {final_command.strip()}")
                  cv2.imshow("Processed Frame", processed_frame)

                  if cv2.waitKey(1) & 0xFF == ord('q'):
                        break
            
      except KeyboardInterrupt:
            print("Stopping script...")
      finally:
            if lidar:
                  lidar.stop()
                  lidar.stop_motor()
                  lidar.disconnect()
            if arduino and arduino.is_open:
                  safe_write(arduino, "S\n")
                  arduino.close()
            cap.release()
            cv2.destroyAllWindows()
            print("Cleanup done.")

if __name__ == "__main__":
      main()

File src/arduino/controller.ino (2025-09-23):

#include <Servo.h>
#include <Wire.h>
#include "SSD1306Ascii.h"
#include "SSD1306AsciiWire.h"
#include <Adafruit_MPU6050.h>
#include <QMC5883LCompass.h>

#define servoPin 11
#define MotorF 6
#define MotorB 5
#define BUTTON1 13
#define GreenLedPin A3
#define RedLedPin A2
#define Display_I2C_ADDRESS 0x3C

// Motor control variables
int motor_forward_speed = 90;
int servo_angle = 110;

// Sensor objects
Adafruit_MPU6050 mpu;
QMC5883LCompass compass;
Servo myservo;
SSD1306AsciiWire oled;

// Timing for sensor readings
unsigned long previousMillis = 0;
const long interval = 100;  // Send sensor data every 100ms
bool start = 0;

void setup() {
  Serial.begin(9600);   // Arduino and Jetson should use the same baud rate

  Wire.begin();
  Wire.setClock(400000L);

  // Initialize OLED display
  oled.begin(&Adafruit128x64, Display_I2C_ADDRESS);
  oled.setFont(System5x7);
  oled.clear();
  oled.setCursor(0, 0);
  oled.print("Starting up...");

  // Initialize MPU6050
  if (!mpu.begin()) {
    oled.setCursor(0, 3);
    oled.print("MPU Fail!");
    while (1) {
      digitalWrite(RedLedPin, HIGH);
      delay(500);
      digitalWrite(RedLedPin, LOW);
      delay(500);
    }
  }

  // Initialize QMC5883L
  compass.init();

  // Set up pins
  pinMode(GreenLedPin, OUTPUT);
  pinMode(RedLedPin, OUTPUT);
  pinMode(MotorF, OUTPUT);
  pinMode(MotorB, OUTPUT);
  pinMode(BUTTON1, INPUT);
  myservo.attach(servoPin);

  // Initial state
  myservo.write(100);
  analogWrite(MotorF, 0);
  analogWrite(MotorB, 0);

  oled.clear();
  oled.setCursor(0, 0);
  oled.print("Awaiting Start");
}

void loop() {
  connectionStatus();
  analogWrite(MotorF, 0);
  analogWrite(MotorB, 0);

  // Check if the start button is pressed
  if (digitalRead(BUTTON1) == HIGH) {
    start = 1;
    oled.clear();
    oled.setCursor(0, 0);
    oled.print("Autonomy On");
    digitalWrite(GreenLedPin, HIGH);

    while (start != 0) {
      if (digitalRead(BUTTON1) == HIGH) {
        start = 0;
        delay(1000);
      }

      // Sends sensor data to the Jetson Nano for processing
      sendSensorData();
      
      // Receives the final angle command from the Jetson Nano
      receiveMotorCommand();

      // Updates the servo angle
      myservo.write(servo_angle);
      
      // Sets the motor speed to a constant value
      analogWrite(MotorF, 90);
      analogWrite(MotorB, 0);
    }
  }

  digitalWrite(GreenLedPin, LOW);
}

void sendSensorData() {
  sensors_event_t a, g, temp;
  mpu.getEvent(&a, &g, &temp);

  compass.read();
  float heading = compass.getAzimuth();

  // Format and send data to the Jetson Nano
  Serial.print("GY:");
  Serial.print(g.gyro.y);
  Serial.print(",H:");
  Serial.print(heading);
  Serial.print(",AX:");
  Serial.print(a.acceleration.x);
  Serial.print(",AY:");
  Serial.print(a.acceleration.y);
  Serial.print(",AZ:");
  Serial.print(a.acceleration.z);
  Serial.print(",GX:");
  Serial.print(g.gyro.x);
  Serial.print(",GZ:");
  Serial.print(g.gyro.z);
  Serial.println();
}

void connectionStatus(){
  if (Serial.available()) {
    String data = Serial.readStringUntil('\n');

    if (data.startsWith("RL")) {
      digitalWrite(RedLedPin, HIGH);
      return;
    }
  }
}

void receiveMotorCommand() {
  if (Serial.available()) {
    String data = Serial.readStringUntil('\n');

    // Check for "STOP" command
    if (data.startsWith("S")) {
      analogWrite(MotorF, 0);
      analogWrite(MotorB, 0);
      return;
    }

    if (data.startsWith("RL")) {
      digitalWrite(RedLedPin, HIGH);
      return;
    }

    // Expected format: "A<servo_angle>"
    int a_index = data.indexOf("A");

    if (a_index != -1) {
      String angleStr = data.substring(a_index + 1);
      int received_angle = angleStr.toInt();
      
      // Ensure values are within a safe range
      servo_angle = constrain(received_angle, 75, 145);
    }
  }
}
